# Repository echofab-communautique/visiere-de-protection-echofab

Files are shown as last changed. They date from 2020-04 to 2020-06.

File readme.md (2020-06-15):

# Equipement de protection individuelle/Visière de protection échofab

⚠️ ENGLISH Version is available below - - [GO TO ENGLISH](#personal-protective-equipmentechofab-protective-visor)

> **Visière de protection échofab** - version augmentée basée sur le modèle open source Proto Shields de Protohaven, équivalent en découpe laser du modèle PRUSA.  
> **Premier lieu de fabrication :** Echofab    
> **Objectif :** protection contre la maladie Covid-19   
> **Date de création :** 1 avril 2020   

## Sommaire

- [Introduction](#Introduction)
- [Contexte](#Contexte)
- [Evolution du modèle](#Evolution-du-modèle)
- [Méthode de fabrication](#méthode-de-fabrication--la-découpe-laser)
- [Paramètres de fabrication](#paramètres-de--fabrication)
- [Matériaux](#materiaux)
- [Fabrication des pièces de la visière](#fabrication-des-pièces-de-la-visière)
- [Montage de la visière](#montage-de-la-visière)
- [Processus de fabrication à l’échelle](#processus-de-fabrication-à-léchelle)
- [Recommandations générales](#Recommandations-générales)
- [Conseil de santé](#Conseil-de-santé)
- [Information complémentaire](#Information-complémentaire)
- [Partenariats](#Partenariats)

Visière Echofab2

visiere-triptyque

## Introduction
Conception révisée et testée par l’hôpital du Sacré Coeur, Centre intégré universitaire de santé et de services sociaux du Nord-de-l'Île-de-Montréal en date du 01/04/2020
Version qui a été co-conçue avec utilisateurs en milieu hospitalier.

## Contexte

En réponse à l’appel du gouvernement du Canada, du Québec et le réseau de la santé, **Communautique**, avec son équipe et ses proches collaborateurs, a commencé la production d'un modèle de visière de protection pour les travailleurs de la santé au sein de son Fab Lab **échofab**.

L'initiative d’offrir la capacité de production de notre Fab Lab **échofab** au service de l’intérêt général et en particulier celui des travailleurs du réseau de la santé, participe de l’appel de notre Premier Ministre du Canada, l’Hon. Justin Trudeau, à favoriser la réappropriation locale de la production de matériel essentiel, dont ceux nécessaires à la santé. 

**Communautique** est aussi co-organisatrice du prochain Fab City Summit (https://www.facebook.com/FabCityMontreal/). La **Fab City** propose un nouveau modèle urbain, économique et industriel permettant aux villes de produire localement la majorité de ce qu’elles consomment, connectées à un réseau mondial d’autres villes et de territoires qui mettent en place des stratégies similaires. 
La présente pandémie illustre la nécessité de ne pas dépendre essentiellement de circuits d’approvisionnement mondialisés à flux tendus, mais de disposer aussi de ressources plus redondantes et localement contrôlées.

Notre ambition annoncée est de développer le prototype **Fab City Montréal** au District Central de Montréal, ancienne Cité de la Mode (Chabanel).

## Evolution du modèle

**La visière offerte par Communautique** est une version augmentée basée sur le modèle open source Proto Shield de Protohaven, équivalent fabriqué à la découpe laser du modèle open source de Prusa Research 3D printers. Elle sera produite à faible coût, légère, ajustable, réutilisable et disponible immédiatement pour une livraison vers les hôpitaux, cliniques et autres institutions de première ligne.
<a href="https://www.protohaven.org/proto-shield/" target="_blank">`https://www.protohaven.org/proto-shield/`</a>
<a href="https://www.prusaprinters.org/prints/25857-prusa-protective-face-shield-rc2" target="_blank">`https://www.prusaprinters.org/prints/25857-prusa-protective-face-shield-rc2`</a>

## Méthode de fabrication : la découpe laser

Nous avons été contacté par des travailleurs du réseau de la santé afin de nous a sensibilisé à la possibilité d’avoir une visière recyclable. Étant un Fab Lab investi dans le développement durable, nous étions très réceptif. Nous avons eu dès lors une information précieuse sur ce qui pouvait ou non être éventuellement recyclable dans le contexte du milieu de la santé.

Nous avons recherché parmi les solutions entièrement à la découpe laser et trouvé le modèle Proto Shields, de Protohaven, basé sur le modèle PRUSA.

Nous avons fabriqué le Proto Shields, lors d’une visite furtive à notre Lab, avec du plastique de fortune disponible sur place. Nous l’avons comparé à la visière du modèle du CHUM, de là élargi sur les cotés, et retiré un gréement au bas de la visière qui nous semblait peu utile et à risque.

### Téléchargement : Les fichiers .svg peuvent être téléchargés en cliquant sur le bouton "Clone or donwload" en haut de cette page

La bande:
Bande final (1)

La visière:
visiere finiale (1)

## Paramètres de  fabrication 

- **Dimension des plaques :** 13,5'' x 21" pour la visière
, et 24"X 17" pour la couronne



- **Machine de découpe :** Trotec Speedy 300

## Matériaux 

### Matériaux peuvent comprendre : 

**Monture :** PETG (Polyéthylène Téréphtalate Glycolisé) incolore 0.06" ou 0.04"  
**Visière :** PETG incolore 0.02 ou Clear, Impact Modified Acrylic .018 ou Polycarbonate (pas de découpe laser) (les modifiants chocs acryliques transparent), selon disponibilité sur le marché  
**Bande élastique :** plat, 1 cm, pratique et polyvalent. Exemple : <a href="https://www.amazon.ca/-/fr/dp/B086C38L29/ref=sr_1_3" target="_blank">`https://www.amazon.ca/-/fr/dp/B086C38L29/ref=sr_1_3`</a>  

### Propriétés du PETG incolore:
- très bonnes propriétés optiques
- très bonne résistance aux agents chimiques
- transparent anti-buée et anti-éraflures
- confort ajusté
- réutilisabilité possible
- s’usine très facilement et ne nécessitent pas de précautions particulières
- très résistant choc et feu

### Propriétés de l’élastique

- élastique à boutonnière tricotté,
- 3/4" de large
- de couleur de préférence pâle

## Fabrication des pièces de la visière

1- Télécharger les 2 fichiers .svg

2- Configurer la découpe laser  
Visiere: P:100 V:2 F:5000  
Couronne: P100 V:1 F:5000  
Parametres utilisés pour petg  
visière = 0.02" ep  
couronne =0,06" ep  

## Montage de la visière
montage-visiere-x2-cropped-reduced

| Etape #1 | Etape #2 | Etape #3  |
| :---: |:---:| :---:|
|  |  |   |

| Etape #4 | Etape #5 | Etape #6  |
| :---: |:---:| :---:|
|  |  |   |

Résultat final


## Processus de fabrication à l’échelle
Voir les fichiers .svg commencant par "PRODUCTION-"
### Système de levier pour la plieuse du bandeau intérieur
**Objectif : Diminuer la force nécessaire à appliquer sur la matrice et augmenter la précision/répétitivité.**
L’assemblage initial de la plieuse sans levier a été réalisé par Raphael Demers et Lucas (lucas.tisne@gmail.com)

L’ensemble des pièces de cette mise à jour doit être découpé au laser dans du contreplaqué de 0.25’’ à l’exception des piliers verticaux qui sont des 2X4 et des deux supports imprimés en 3D. 

Fichier nécessaires
Fichier Inkscape de découpe pour le laser (Package 5 (1X).svg
Fichier STL pour imprimer en 3D les supports. Imprimer 2 fois. (Support V4-2.stl) 
Fichier de l’assemblage en 3D (STP) : Levier V4_1.stp
Ferronnerie  
Levier et bielle : Vis à métal 5/16’’ pour connecter la bielle et le levier aux pièces en 3D. Pas besoin d’écrou comme la vis s’encastre dans le plastique.
Supports en plastique imprimés en 3D : Attachés par des vis métal en #6-32, rondelles et écrous. 

## Recommandations générales

## Conseil de santé

## Information complémentaire

## Partenariats
  
Merci de votre solidarité !  

<a href="https://takdi.com/" target="_blank">Tak Design</a>
<a href="http://www.hyperboreas.com/" target="_blank"> HyperBoreas</a>
<a href="http://www.procedurable.com/" target="_blank"> Procédurable</a>
<a href="http://www.percolab.com/" target="_blank"> Percolab</a>
<a href="https://fablabdupec.com/" target="_blank"> Fab Lab du PEC</a>
<a href="https://www.fablabldi.com/description" target="_blank"> Fab Lab LDI</a>
<a href="https://www.nanogrande.com/" target="_blank"> Nanogrande</a>
<a href="http://www.lamour.com/" target="_blank"> Groupe Lamour</a>
<a href="http://www.fybon.com/" target="_blank"> Fybon Nonwovens</a>
<a href="https://district-central.ca/" target="_blank"> District Central</a>
<a href="https://www.adiaccelerator.com/" target="_blank"> ADI Accélérateur</a>
<a href="https://theconversation.com/profiles/pierrot-peladeau-693198" target="_blank"> Pierrot Péladeau</a>
<a href="http://www.rotaract-idm.com/" target="_blank"> Rotaract Club de l’Île de Montréal</a>
Robert Dumontet
<a href="http://www.lucprevost.com/" target="_blank"> Luc Prévost </a>

---  

# Personal Protective Equipment/Echofab Protective Visor

> **Echofab Protective Visor** -augmented version based on the open source Proto Shields model from Protohaven, equivalent in laser cutting of the PRUSA model.  
> **First place of manufacture :** Echofab    
> **Objective :** protection against Covid-19 disease   
> **Creation date :** April 1st, 2020  

## Table of content

- [Background](#Background)
- [Evolution of the model](#evolution-of-the-model)
- [Manufacturing method: laser cutting](#manufacturing-method-laser-cutting)
- [Manufacturing parameters](#Manufacturing-parameters)
- [Materials](#materials)
- [Manufacturing of Face shield parts](#Manufacturing-of-Face-shield-parts)
- [Face shield mounting](#Face-shield-mounting)
- [Manufacturing process to scale](#Manufacturing-process-to-scale)
- [General recommendations](#General-recommendations)
- [Health Advice](#Health-Advice)
- [Further information](#Further-information)
- [Partnerships](#Partnerships)

Visière Echofab2

visiere-triptyque

## Introduction
Design revised and tested by Sacré Coeur Hospital, Centre intégré universitaire de santé et de services sociaux du Nord-de-l'Île-de-Montréal as of 01/04/2020
Version that was co-designed with hospital users.

## Background

In response to a call from the Government of Canada, Quebec and the health network, **Communautique**, with its team and close collaborators, has begun production of a protective visor model for health care workers within its **échofab** Fab Lab.

The initiative to offer the production capacity of our **échofab** Fab Lab to serve the general interest and in particular that of health care workers, is part of the appeal of our Prime Minister of Canada, the Hon. Justin Trudeau, to promote the local reappropriation of the production of essential materials, including those necessary for health.  

**Communautique** is also co-organizing the next Fab City Summit (https://www.facebook.com/FabCityMontreal/). The **Fab City** proposes a new urban, economic and industrial model allowing cities to produce locally the majority of what they consume, connected to a global network of other cities and territories that are implementing similar strategies. 
The current pandemic illustrates the need not to depend primarily on globalized just-in-time supply channels, but also to have more redundant and locally controlled resources.

Our announced ambition is to develop the **Fab City Montréal** prototype in the Central District of Montreal, former Cité de la Mode (Chabanel).

## Evolution of the model

**The visor offered by Communautique** is an augmented version based on the open source Proto Shield model from Protohaven, the laser-cut equivalent of the open source Prusa Research 3D printers model. It will be produced at low cost, lightweight, adjustable, reusable and immediately available for delivery to hospitals, clinics and other front-line institutions.  
<a href="https://www.protohaven.org/proto-shield/" target="_blank">`https://www.protohaven.org/proto-shield/`</a>  
<a href="https://www.prusaprinters.org/prints/25857-prusa-protective-face-shield-rc2" target="_blank">`https://www.prusaprinters.org/prints/25857-prusa-protective-face-shield-rc2`</a>  

## Manufacturing method: laser cutting

We were contacted by workers in the health network to raise awareness to the possibility of having a recyclable visor. Being a Fab Lab invested in sustainable development, we were very receptive. We then had valuable information on what could or could not be recyclable in the context of the health sector.

We searched among the solutions entirely using laser cutting and found the Proto Shields model, from Protohaven, based on the PRUSA model.

We made the Proto Shields, during a quick visit to our Lab, with makeshift plastic available on site. We compared it to the visor of the CHUM model, from there we widened it on the sides, and removed a rigging at the bottom of the visor which seemed to us to be of little use and risky.

### Download : .svg files can be donwloaded by clicking on "Clone or donwload" button at the top of this page

The frame:
Bande final (1)

The visor:
visiere finiale (1)

## Manufacturing parameters 

- **Plates Dimension :** 13,5'' x 21" for the visor
, et 24"X 17" for the frame



- **Cutting machine :** Trotec Speedy 300

## Materials

### Materials may include:  

**Frame :** Colorless PETG (Polyethylene Terephthalate Glycolate) 0.06" or 0.04"  
**Visor :** Colorless PETG 0.02 or Clear, Impact Modified Acrylic .018 or Polycarbonate (no laser cutting) (Clear Acrylic Impact Modifiers), depending on market availability  
**Elastic band :** flat, 1 cm, practical and versatile. Example: <a href="https://www.amazon.ca/-/fr/dp/B086C38L29/ref=sr_1_3" target="_blank">`https://www.amazon.ca/-/fr/dp/B086C38L29/ref=sr_1_3`</a>  

### Properties of colourless PETG:
- very good optical properties
- very good resistance to chemical agents
- transparent, anti-fog and anti-scratch
- fitted comfort
- reusability possible
- very easy to machine and does not require any special precautions
- very shock and fire resistant

### Properties of the elastic

- elastic with knitted buttonhole,
- 3/4" width
- preferably pale color

## Manufacturing of Face shield parts

1- Donwlond the 2 .svg files

2- Configure the laser cutting machine  
Visor: P:100 V:2 F:5000  
Frame: P100 V:1 F:5000  
Parameters used for petg  
Visor = 0.02" ep  
Frame =0,06" ep  

## Face shield mounting

montage-visiere-x2-cropped-reduced

| Step #1 | Step #2 | Step #3  |
| :---: |:---:| :---:|
|  |  |   |

| Step #4 | Step #5 | Step #6  |
| :---: |:---:| :---:|
|  |  |   |

Final Result


## Manufacturing process to scale
See .svg files beginning with "PRODUCTION-"
### Leverage system for the interior headband folder
**Objective: Decrease the force required to apply to the matrix and increase the precision / repeatability.**
The initial assembly of the leverless folder was carried out by Raphael Demers and Lucas (lucas.tisne@gmail.com)

All of the parts in this update must be laser cut from 0.25 ’’ plywood with the exception of the vertical pillars which are 2X4 and two 3D printed media.

File required:
Inkscape laser cutting file (Package 5 (1X) .svg
STL file to 3D print the supports. Print 2 times. (Support V4-2.stl)
3D assembly file (STP): Lever V4_1.stp
Ironwork
Lever and connecting rod: 5/16 '' metal screw to connect the connecting rod and lever to 3D parts. No need for a nut as the screw fits into the plastic.
Plastic supports printed in 3D: Attached by metal screws in # 6-32, washers and nuts.

## General recommendations

## Health Advice

## Further information

## Partnerships
  
Thank you for your solidarity!

<a href="https://takdi.com/" target="_blank">Tak Design</a>
<a href="http://www.hyperboreas.com/" target="_blank"> HyperBoreas</a>
<a href="http://www.procedurable.com/" target="_blank"> Procédurable</a>
<a href="http://www.percolab.com/" target="_blank"> Percolab</a>
<a href="https://fablabdupec.com/" target="_blank"> Fab Lab du PEC</a>
<a href="https://www.fablabldi.com/description" target="_blank"> Fab Lab LDI</a>
<a href="https://www.nanogrande.com/" target="_blank"> Nanogrande</a>
<a href="http://www.lamour.com/" target="_blank"> Groupe Lamour</a>
<a href="http://www.fybon.com/" target="_blank"> Fybon Nonwovens</a>
<a href="https://district-central.ca/" target="_blank"> District Central</a>
<a href="https://www.adiaccelerator.com/" target="_blank"> ADI Accélérateur</a>
<a href="https://theconversation.com/profiles/pierrot-peladeau-693198" target="_blank"> Pierrot Péladeau</a>
<a href="http://www.rotaract-idm.com/" target="_blank"> Rotaract Club de l’Île de Montréal</a>
Robert Dumontet
<a href="http://www.lucprevost.com/" target="_blank"> Luc Prévost </a>

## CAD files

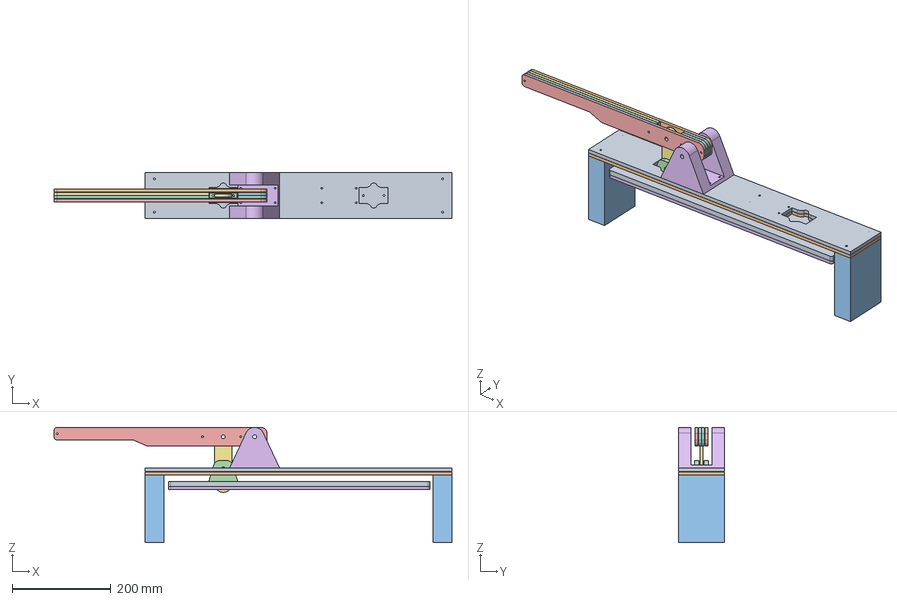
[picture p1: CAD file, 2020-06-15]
systeme_levier/Levier V4_1.stp
806.2 x 92.9 x 233.5 mm

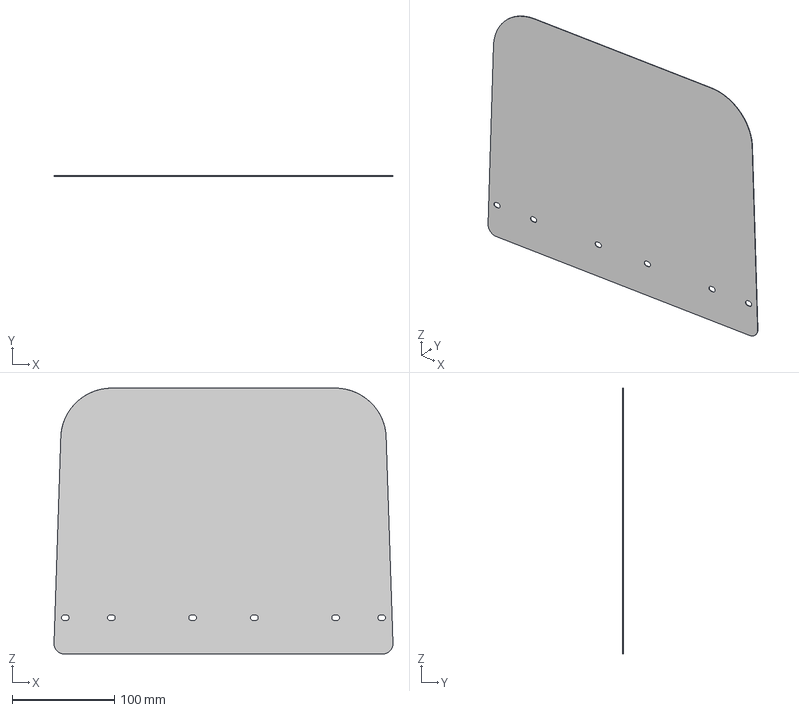
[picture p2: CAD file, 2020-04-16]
visiere finale.step
331.6 x 0.508 x 260.1 mm

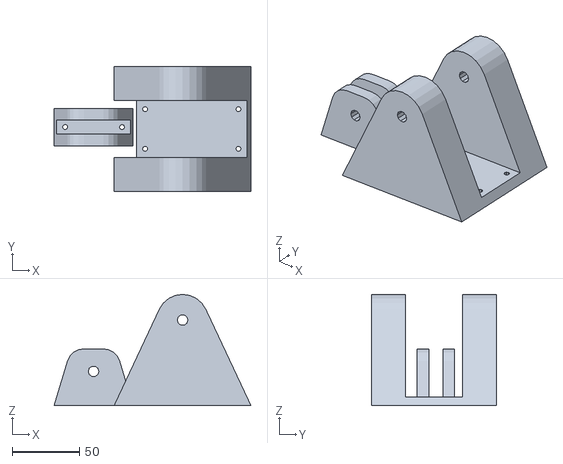
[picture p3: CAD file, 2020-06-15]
systeme_levier/Support V4-2.stl
146.2 x 92.9 x 82.5

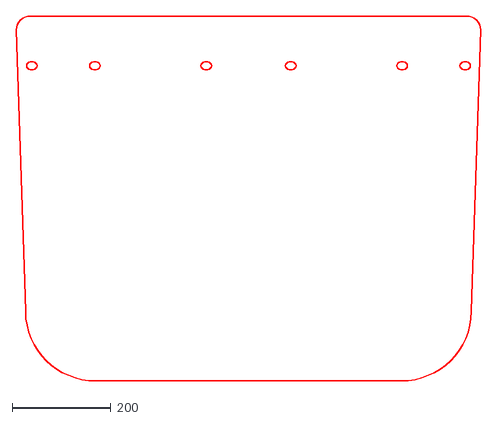
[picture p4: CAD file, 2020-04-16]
visiere finiale.dxf
939.1 x 738.0
